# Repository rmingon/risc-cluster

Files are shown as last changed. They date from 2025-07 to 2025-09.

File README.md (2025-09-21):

# RISC-V Cluster Project

A distributed computing cluster based on CH32V RISC-V microcontrollers with Ethernet connectivity.

[HACKADAY](https://hackaday.io/project/204036-13ghz-for-only-10-bucks)

[TINDIE](https://www.tindie.com/products/rmingon/risc-v-cluster-13ghz-combined/)

REAL WORK

## Overview

This project implements a cluster computing system using multiple CH32V microcontrollers connected via Ethernet. The system features a master controller (CH32V307RCT6) that coordinates with multiple worker nodes (CH32V003F4P6) to form a distributed computing network.

## Project pictures

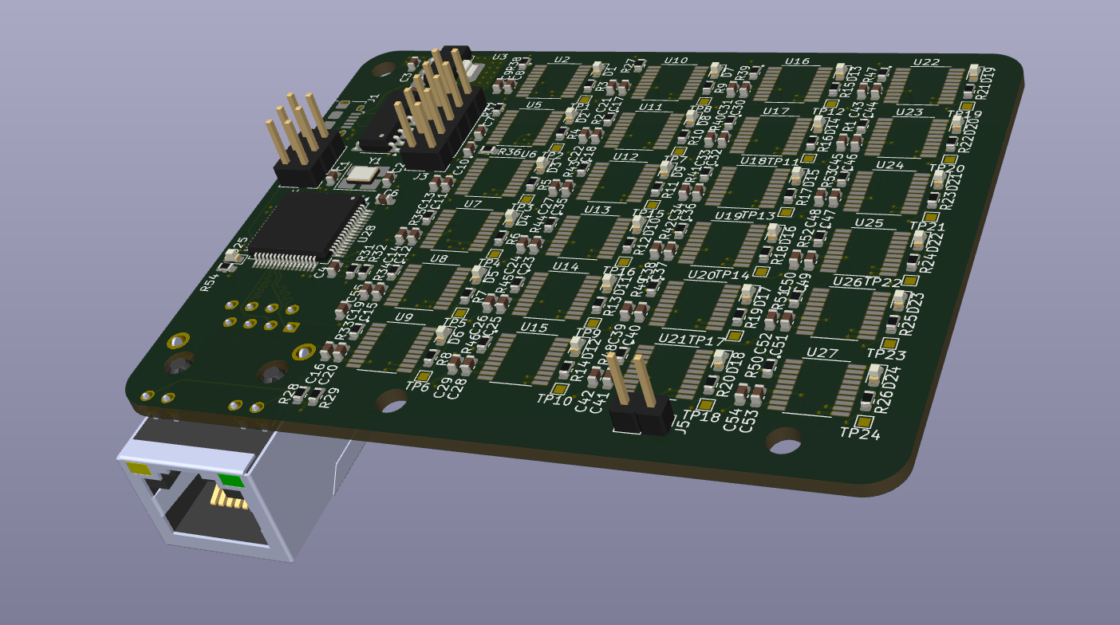
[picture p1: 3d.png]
3D

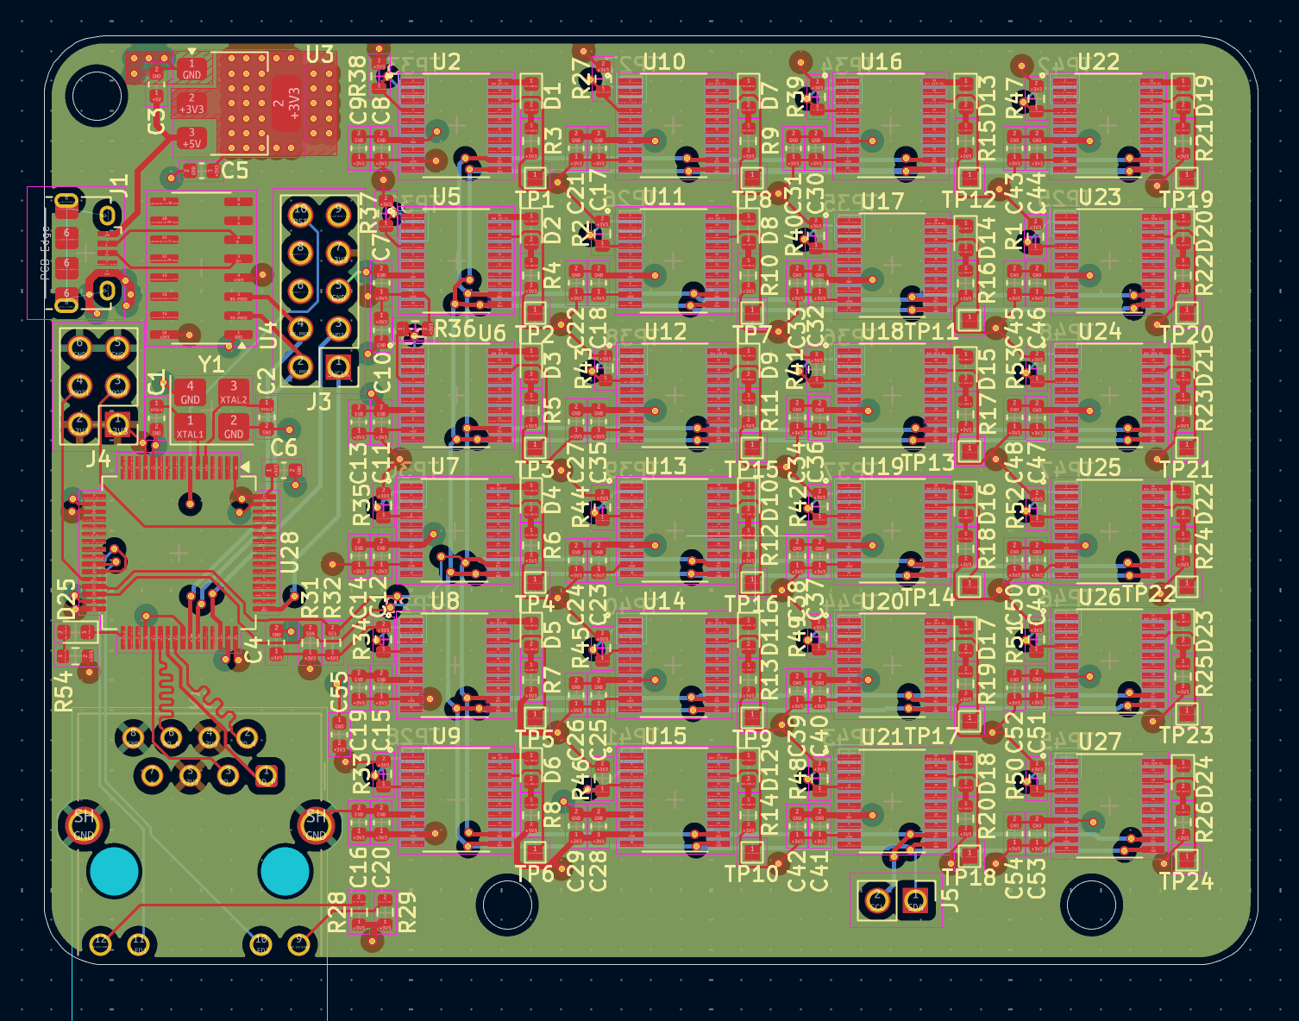
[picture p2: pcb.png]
pcb

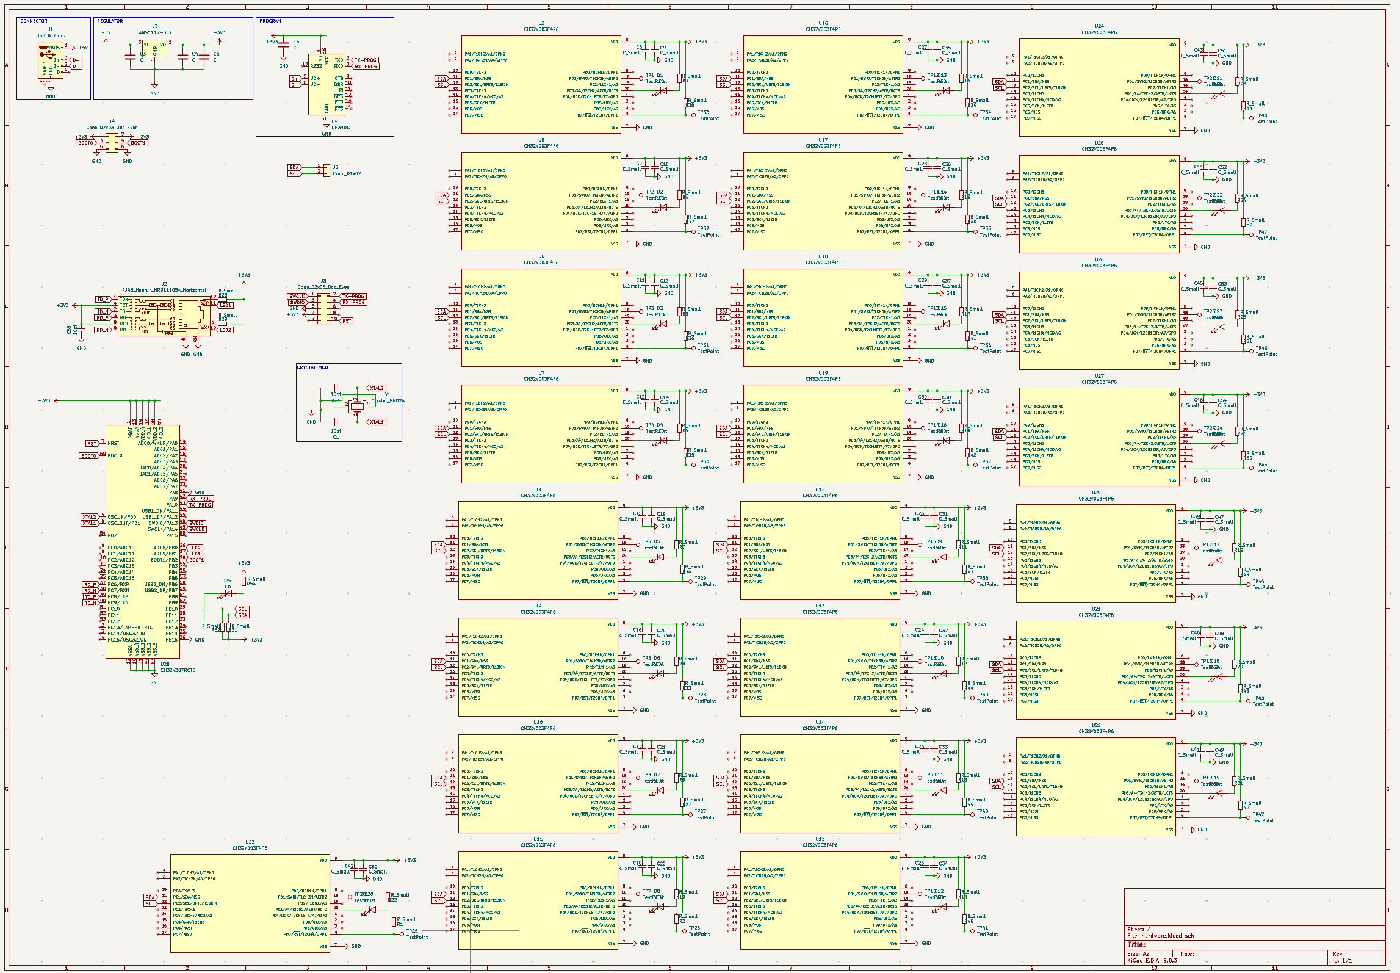
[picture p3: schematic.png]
schematic


## Hardware Design

### Master Controller

- **MCU**: CH32V307RCT6 (64-pin LQFP)
- **Features**:
  - RISC-V core with Ethernet MAC
  - USB connectivity for debugging and programming
  - Ethernet port (RJ45) for network communication
  - Power regulation (3.3V via AMS1117)

### Worker Nodes

- **MCU**: CH32V003F4P6 (24 units)
- **Features**:
  - Compact RISC-V microcontrollers
  - Individual LED indicators
  - Test points for debugging
  - Distributed across the PCB

### Key Components

- **Ethernet**: RJ45 connector with integrated magnetics
- **USB**: Micro-B connector for programming and debug
- **Power**: 3.3V regulation from USB input
- **Debug**: CH340C USB-to-UART bridge
- **Connectors**: Programming headers for JTAG/SWD access

## Project Structure

```
risc-cluster/
├── hardware/                 # KiCad PCB design files
│   ├── hardware.kicad_*     # Main PCB design files
│   ├── production/          # Manufacturing files
│   │   ├── bom.csv         # Bill of Materials
│   │   ├── positions.csv   # Pick and place data
│   │   └── hardware.zip    # Gerber files
│   └── hardware-backups/   # Design history backups
└── master/                  # Master controller firmware
    ├── Core/               # RISC-V core files
    ├── Debug/              # Debug utilities
    ├── Peripheral/         # CH32V30x peripheral drivers
    ├── Startup/            # Boot code
    └── User/               # Application code
```

## Bill of Materials

| Component | Quantity | Description |
| --- | --- | --- |
| CH32V307RCT6 | 1 | Master RISC-V MCU (LQFP-64) |
| CH32V003F4P6 | 24 | Worker RISC-V MCUs (SOP-20) |
| AMS1117-3.3  | 1 | 3.3V voltage regulator |
| CH340C | 1 | USB-to-UART bridge |
| LEDs | 25 | Status indicators |
| Resistors | 29 | Current limiting (0603) |
| Capacitors | 52 | Decoupling and filtering (0603) |
| Connectors | 5 | USB, Ethernet, programming headers |

## Development Setup

### Hardware Tools

- KiCad 7.0+ for PCB design
- Standard PCB fabrication (4-layer board)
- Pick and place assembly for SMD components

### Software Tools

- MounRiver Studio IDE (for CH32V development)
- WCH-LinkE programmer/debugger
- CH32V peripheral library

## Getting Started

1. **Hardware Assembly**: Use the production files in `hardware/production/` for PCB fabrication
2. **Master Firmware**: Build and flash the master controller code in `master/`
3. **Worker Firmware**: Develop and deploy worker node firmware for distributed tasks
4. **Network Setup**: Configure Ethernet connectivity for cluster communication

## Recent Development

Based on git history, recent work includes:

- Initial PCB layout with CH32V microcontrollers
- Ethernet connectivity implementation
- CH32V307 master controller integration
- MounRiver Studio project setup
- Production file generation

## License

This project is licensed under the CERN Open Hardware Licence Version 2 - Strongly Reciprocal (CERN-OHL-S v2).

The hardware design files are released under CERN-OHL-S v2, which ensures that any modifications or improvements to the hardware design must be shared under the same license terms.

Note: This project uses WCH (Nanjing Qinheng Microelectronics) peripheral libraries for firmware development, which are subject to their own licensing terms.

## Contributing

This is a hardware-software co-design project. Contributions welcome for:

- Firmware optimization
- Hardware design improvements
- Cluster algorithms implementation
- Documentation and examples

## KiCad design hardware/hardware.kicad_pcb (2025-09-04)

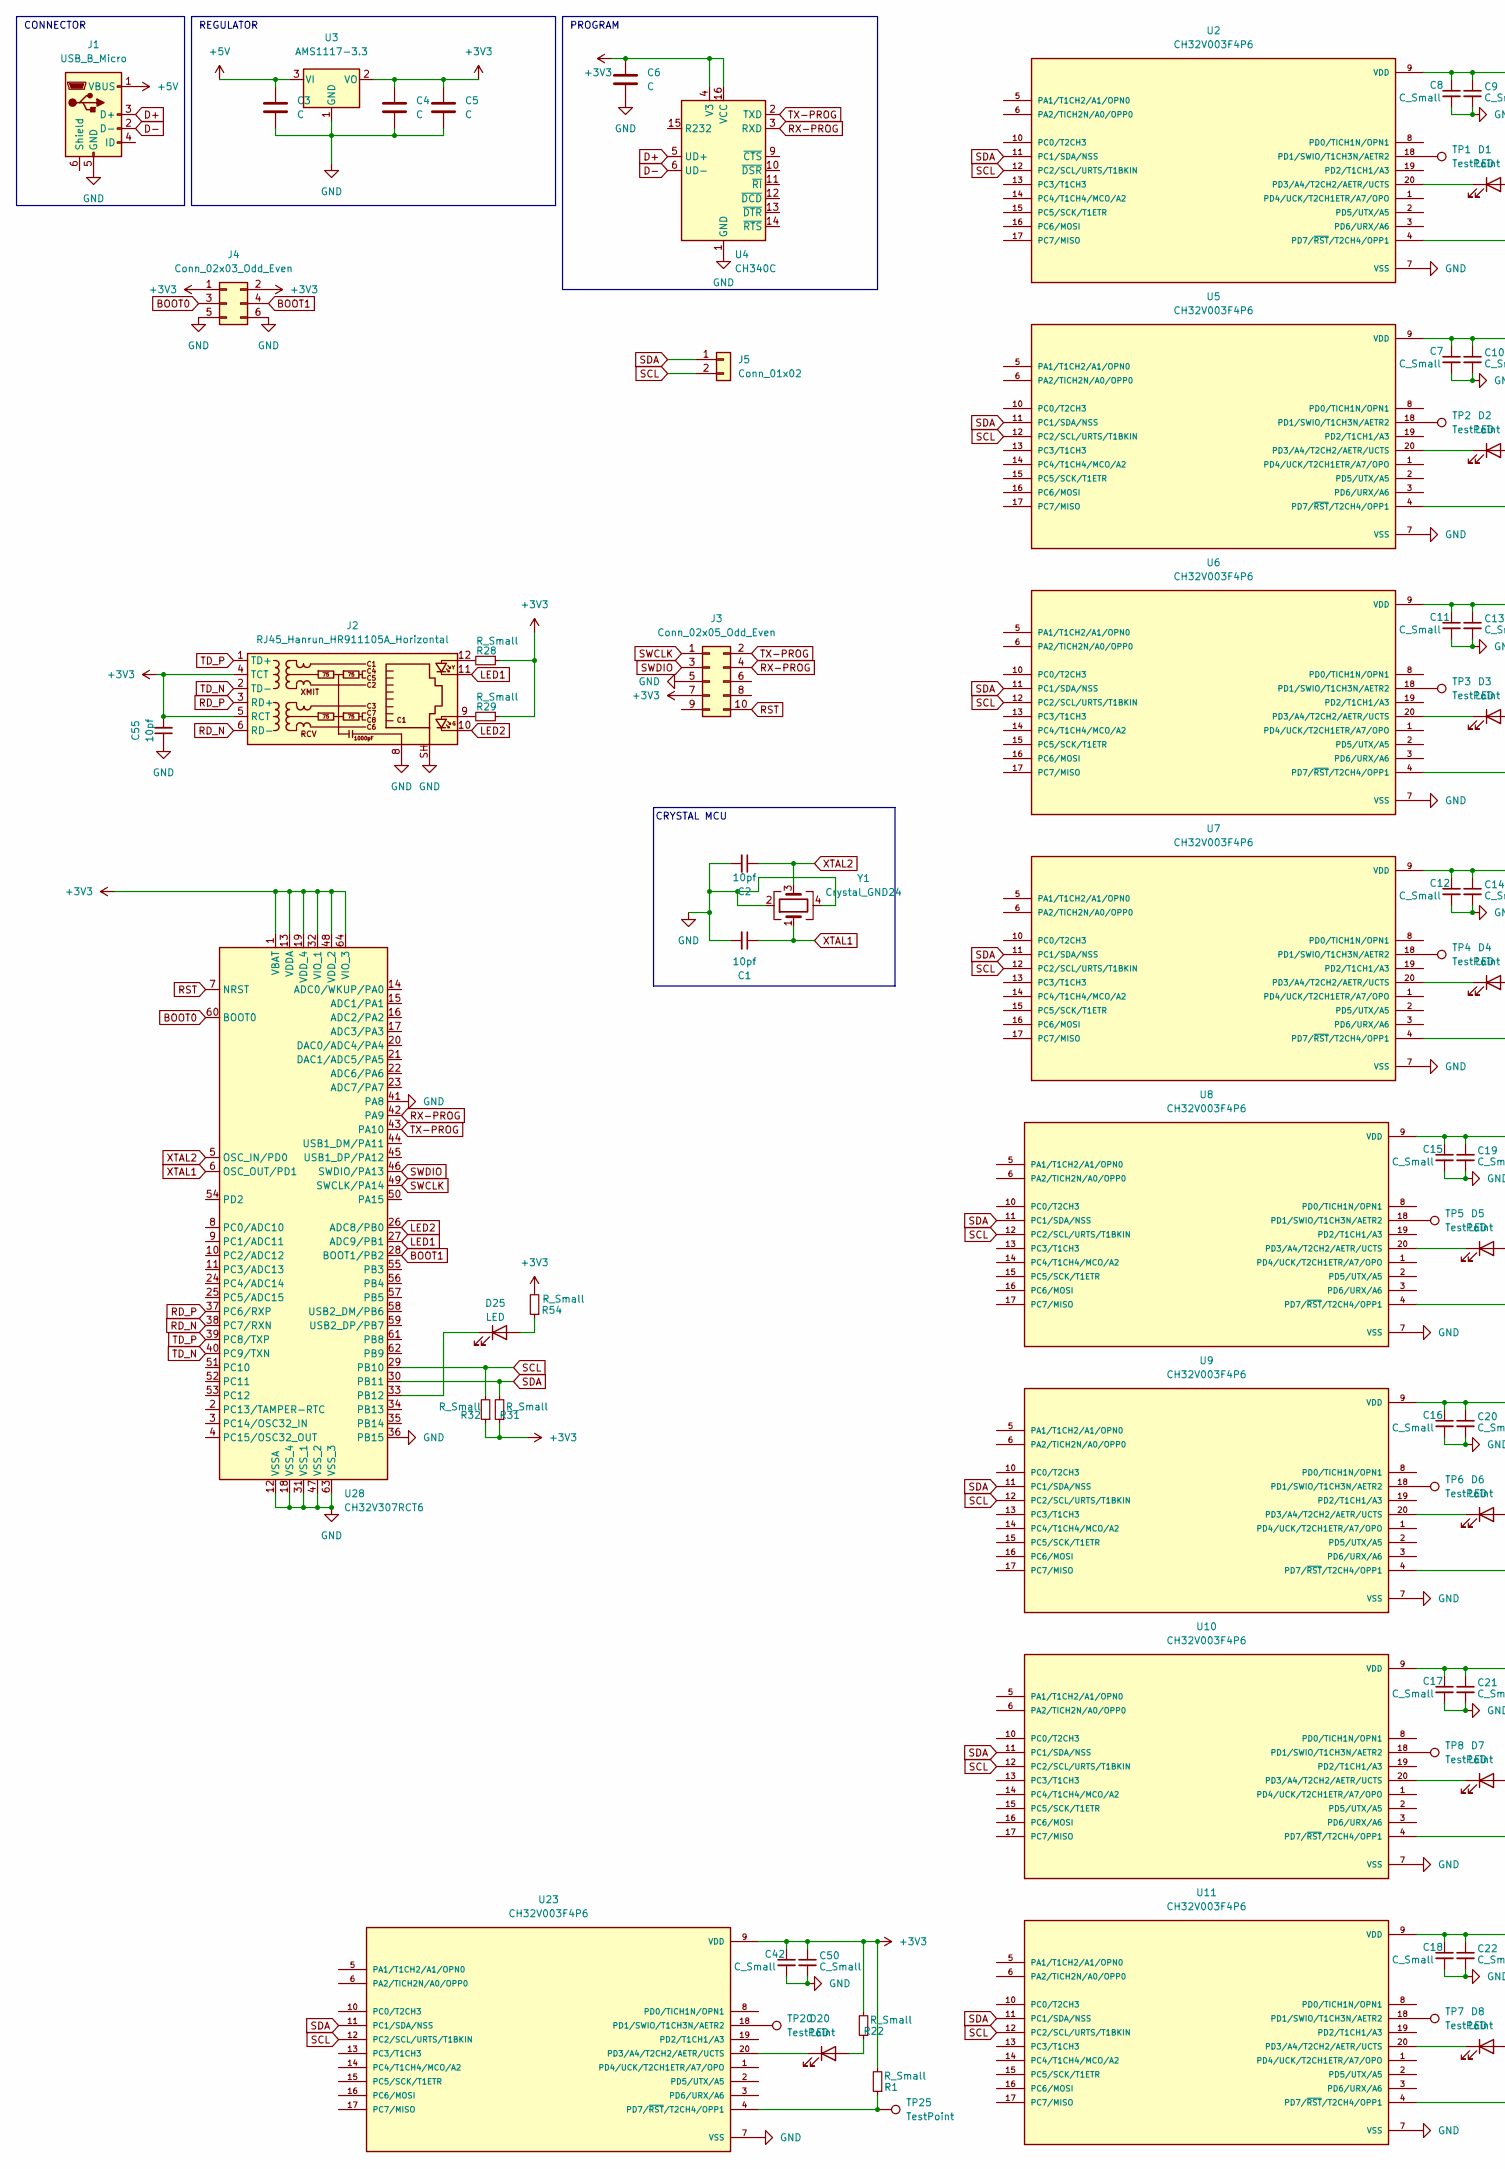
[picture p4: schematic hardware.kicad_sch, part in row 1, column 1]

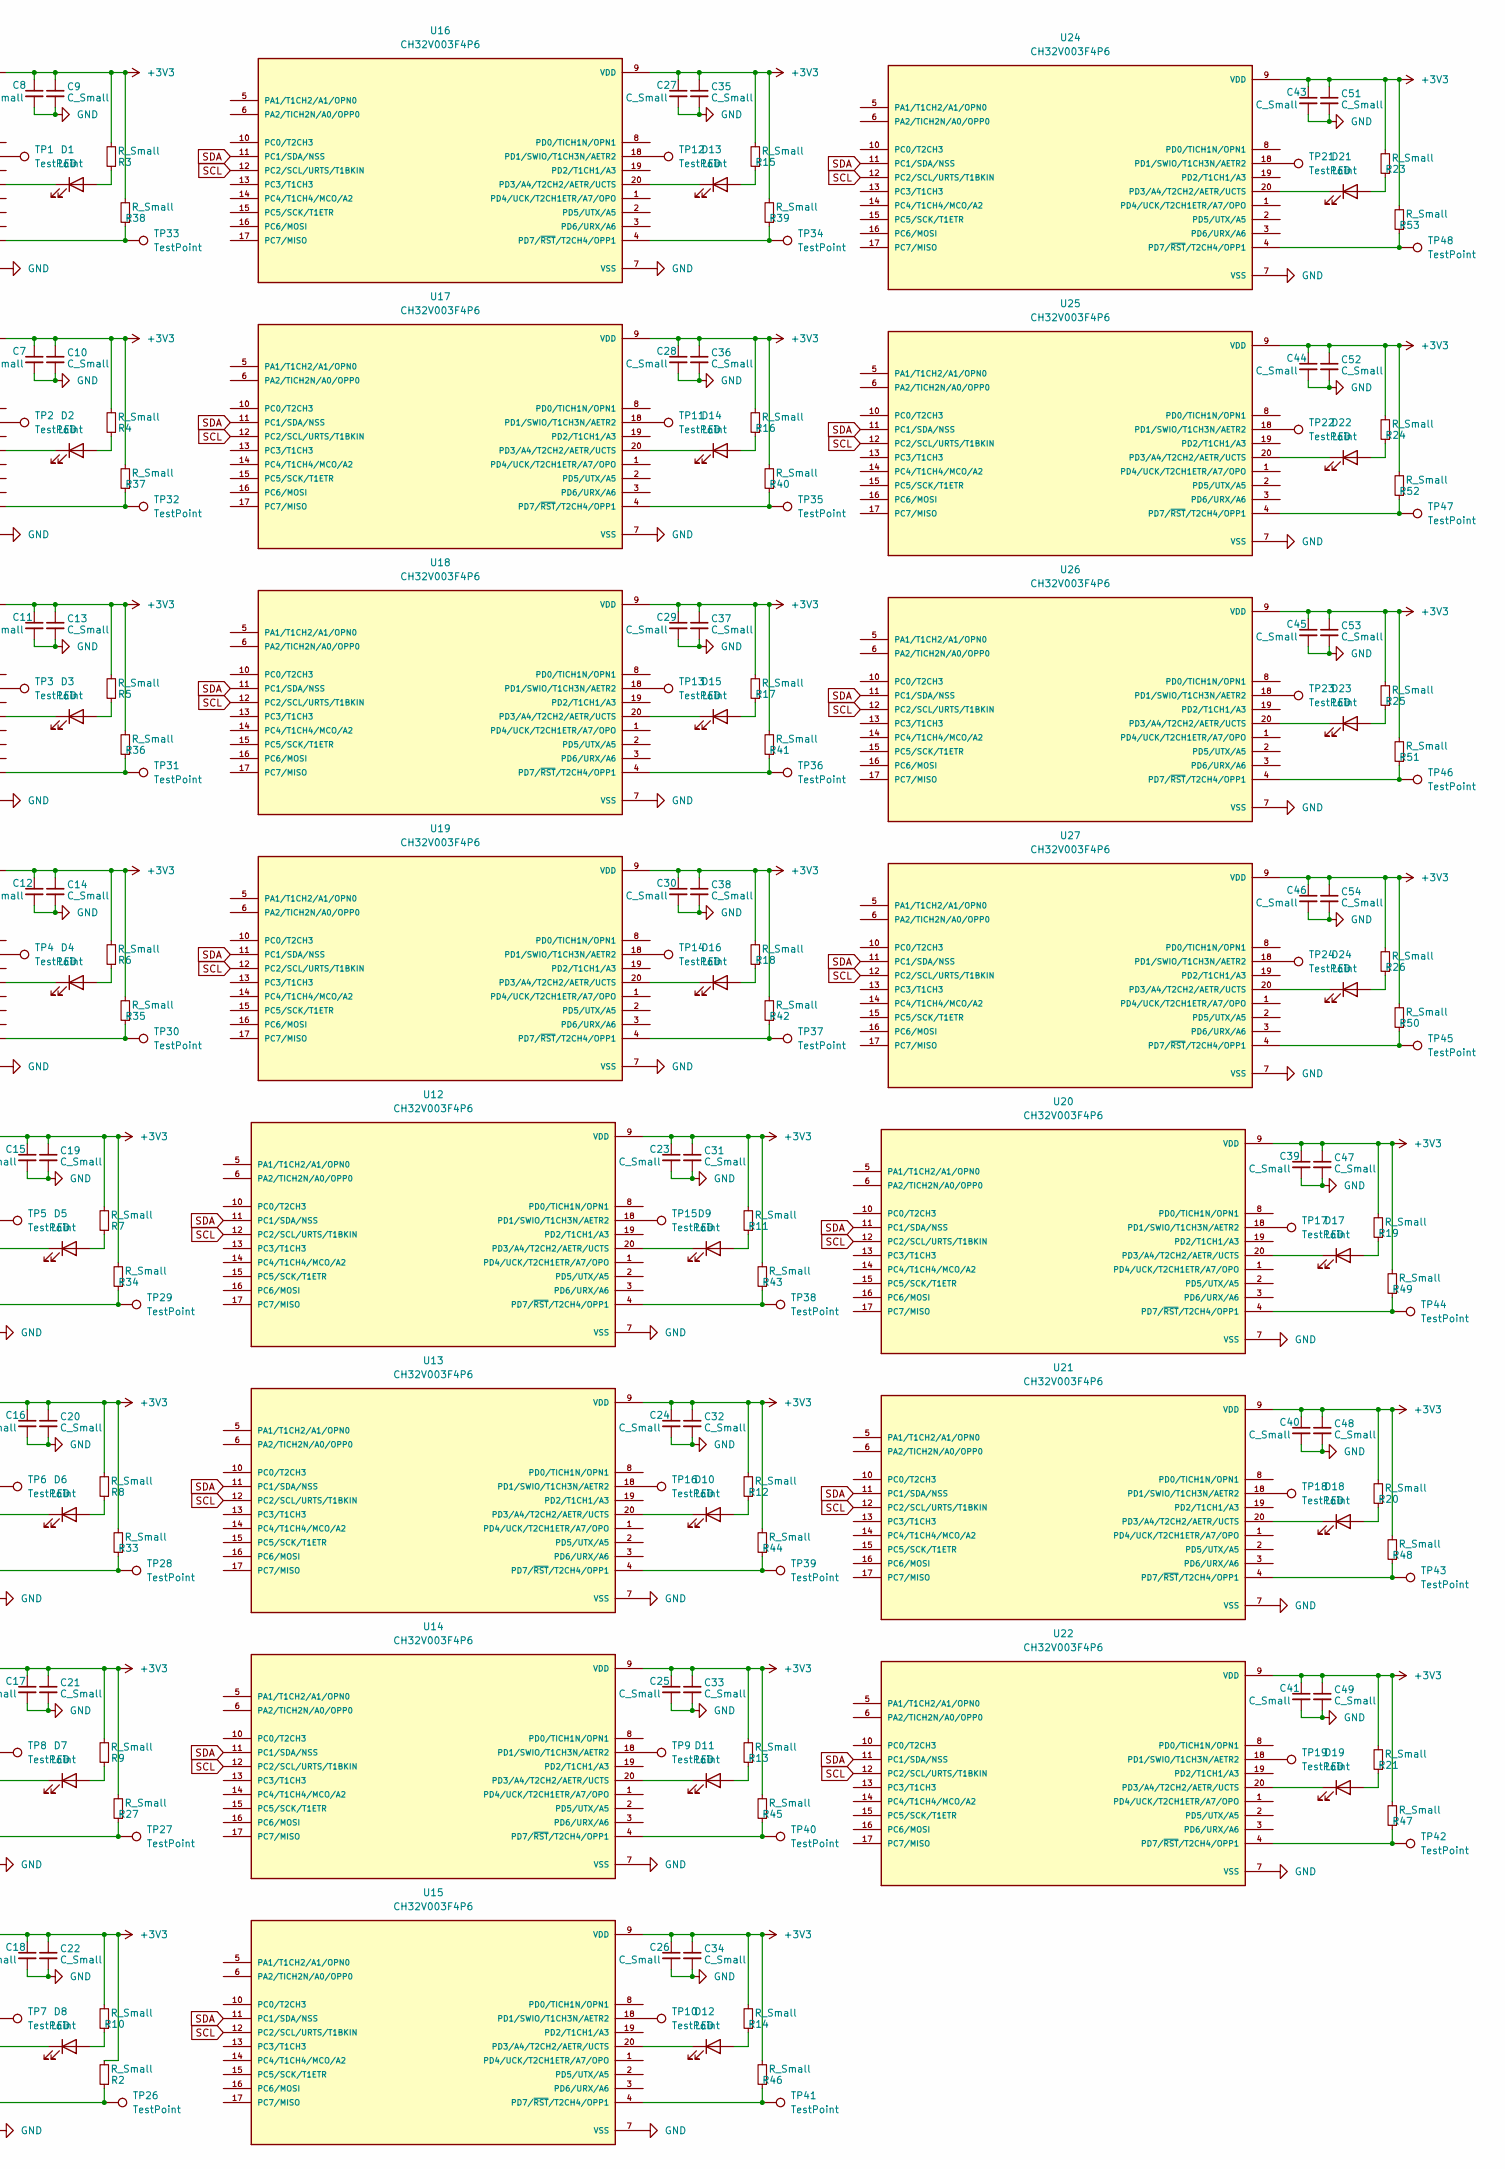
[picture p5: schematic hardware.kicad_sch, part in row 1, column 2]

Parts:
C1, C2, C55: 10pf; C_0603_1608Metric; LCSC C106245
C3, C4, C5, C6: C; C_0603_1608Metric
C7, C8, C9, C10, C11, C12, C13, C14, C15, C16, C17, C18, C19, C20, C21, C22, C23, C24, C25, C26, C27, C28, C29, C30, C31, C32, C33, C34, C35, C36, C37, C38, C39, C40, C41, C42, C43, C44, C45, C46, C47, C48, C49, C50, C51, C52, C53, C54: C_Small; C_0603_1608Metric
D1, D2, D3, D4, D5, D6, D7, D8, D9, D10, D11, D12, D13, D14, D15, D16, D17, D18, D19, D20, D21, D22, D23, D24, D25: LED; LED_0603_1608Metric
J1: USB_B_Micro; USB_Micro-B_Amphenol_10118194_Horizontal
J2: RJ45_Hanrun_HR911105A_Horizontal
J3: Conn_02x05_Odd_Even; PinHeader_2x05_P2.54mm_Vertical
J4: Conn_02x03_Odd_Even; PinHeader_2x03_P2.54mm_Vertical
J5: Conn_01x02; PinHeader_1x02_P2.54mm_Vertical
R1, R2, R3, R4, R5, R6, R7, R8, R9, R10, R11, R12, R13, R14, R15, R16, R17, R18, R19, R20, R21, R22, R23, R24, R25, R26, R27, R28, R29, R31, R32, R33, R34, R35, R36, R37, R38, R39, R40, R41, R42, R43, R44, R45, R46, R47, R48, R49, R50, R51, R52, R53, R54: R_Small; R_0603_1608Metric
TP1, TP2, TP3, TP4, TP5, TP6, TP7, TP8, TP9, TP10, TP11, TP12, TP13, TP14, TP15, TP16, TP17, TP18, TP19, TP20, TP21, TP22, TP23, TP24, TP25, TP26, TP27, TP28, TP29, TP30, TP31, TP32, TP33, TP34, TP35, TP36, TP37, TP38, TP39, TP40, TP41, TP42, TP43, TP44, TP45, TP46, TP47, TP48: TestPoint; TestPoint_Pad_1.0x1.0mm
U2, U5, U6, U7, U8, U9, U10, U11, U12, U13, U14, U15, U16, U17, U18, U19, U20, U21, U22, U23, U24, U25, U26, U27: CH32V003F4P6; SOP65P640X121-20N; PARTREV 1.4
U3: AMS1117-3.3; SOT-223-3_TabPin2
U4: CH340C; SOIC-16_3.9x9.9mm_P1.27mm
U28: CH32V307RCT6; LQFP-64_10x10mm_P0.5mm
Y1: Crystal_GND24; Crystal_SMD_3225-4Pin_3.2x2.5mm_HandSoldering

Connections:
+3V3: C4.1, C5.1, C6.1, C7.1, C8.1, C9.1, C10.1, C11.1, C12.1, C13.1, C14.1, C15.1, C16.1, C17.1, C18.1, C19.1, C20.1, C21.1, C22.1, C23.1, C24.1, C25.1, C26.1, C27.1, C28.1, C29.1, C30.1, C31.1, C32.1, C33.1, C34.1, C35.1, C36.1, C37.1, C38.1, C39.1, C40.1, C41.1, C42.1, C43.1, C44.1, C45.1, C46.1, C47.1, C48.1, C49.1, C50.1, C51.1, C52.1, C53.1, C54.1, C55.2, J2.4 (TCT), J2.5 (RCT), J3.7, J4.1, J4.2, R1.2, R2.2, R3.2, R4.2, R5.2, R6.2, R7.2, R8.2, R9.2, R10.2, R11.2, R12.2, R13.2, R14.2, R15.2, R16.2, R17.2, R18.2, R19.2, R20.2, R21.2, R22.2, R23.2, R24.2, R25.2, R26.2, R27.2, R28.1, R29.1, R31.1, R32.1, R33.2, R34.2, R35.2, R36.2, R37.2, R38.2, R39.2, R40.2, R41.2, R42.2, R43.2, R44.2, R45.2, R46.2, R47.2, R48.2, R49.2, R50.2, R51.2, R52.2, R53.2, R54.2, U2.9 (VDD), U3.2 (VO), U4.4 (V3), U4.16 (VCC), U5.9 (VDD), U6.9 (VDD), U7.9 (VDD), U8.9 (VDD), U9.9 (VDD), U10.9 (VDD), U11.9 (VDD), U12.9 (VDD), U13.9 (VDD), U14.9 (VDD), U15.9 (VDD), U16.9 (VDD), U17.9 (VDD), U18.9 (VDD), U19.9 (VDD), U20.9 (VDD), U21.9 (VDD), U22.9 (VDD), U23.9 (VDD), U24.9 (VDD), U25.9 (VDD), U26.9 (VDD), U27.9 (VDD), U28.1 (VBAT), U28.13 (VDDA), U28.19 (VDD_4), U28.32 (VIO_1), U28.48 (VDD_2), U28.64 (VIO_3)
+5V: C3.1, J1.1 (VBUS), U3.3 (VI)
BOOT0: J4.3, U28.60 (BOOT0)
BOOT1: J4.4, U28.28 (BOOT1/PB2)
D+: J1.3 (D+), U4.5 (UD+)
D-: J1.2 (D-), U4.6 (UD-)
GND: C1.2, C2.2, C3.2, C4.2, C5.2, C6.2, C7.2, C8.2, C9.2, C10.2, C11.2, C12.2, C13.2, C14.2, C15.2, C16.2, C17.2, C18.2, C19.2, C20.2, C21.2, C22.2, C23.2, C24.2, C25.2, C26.2, C27.2, C28.2, C29.2, C30.2, C31.2, C32.2, C33.2, C34.2, C35.2, C36.2, C37.2, C38.2, C39.2, C40.2, C41.2, C42.2, C43.2, C44.2, C45.2, C46.2, C47.2, C48.2, C49.2, C50.2, C51.2, C52.2, C53.2, C54.2, C55.1, J1.5 (GND), J2.8, J2.SH, J3.5, J4.5, J4.6, U2.7 (VSS), U3.1 (GND), U4.1 (GND), U5.7 (VSS), U6.7 (VSS), U7.7 (VSS), U8.7 (VSS), U9.7 (VSS), U10.7 (VSS), U11.7 (VSS), U12.7 (VSS), U13.7 (VSS), U14.7 (VSS), U15.7 (VSS), U16.7 (VSS), U17.7 (VSS), U18.7 (VSS), U19.7 (VSS), U20.7 (VSS), U21.7 (VSS), U22.7 (VSS), U23.7 (VSS), U24.7 (VSS), U25.7 (VSS), U26.7 (VSS), U27.7 (VSS), U28.12 (VSSA), U28.18 (VSS_4), U28.31 (VSS_1), U28.36 (PB15), U28.41 (PA8), U28.47 (VSS_2), U28.63 (VSS_3), Y1.2, Y1.4
LED1: J2.11, U28.27 (ADC9/PB1)
LED2: J2.10, U28.26 (ADC8/PB0)
unnamed: D1.2 (A), R3.1
unnamed: D1.1 (K), U2.20 (PD3/A4/T2CH2/AETR/UCTS)
unnamed: D2.2 (A), R4.1
unnamed: D2.1 (K), U5.20 (PD3/A4/T2CH2/AETR/UCTS)
unnamed: D3.2 (A), R5.1
unnamed: D3.1 (K), U6.20 (PD3/A4/T2CH2/AETR/UCTS)
unnamed: D4.2 (A), R6.1
unnamed: D4.1 (K), U7.20 (PD3/A4/T2CH2/AETR/UCTS)
unnamed: D5.2 (A), R7.1
unnamed: D5.1 (K), U8.20 (PD3/A4/T2CH2/AETR/UCTS)
unnamed: D6.2 (A), R8.1
unnamed: D6.1 (K), U9.20 (PD3/A4/T2CH2/AETR/UCTS)
unnamed: D7.2 (A), R9.1
unnamed: D7.1 (K), U10.20 (PD3/A4/T2CH2/AETR/UCTS)
unnamed: D8.2 (A), R10.1
unnamed: D8.1 (K), U11.20 (PD3/A4/T2CH2/AETR/UCTS)
unnamed: D9.2 (A), R11.1
unnamed: D9.1 (K), U12.20 (PD3/A4/T2CH2/AETR/UCTS)
unnamed: D10.2 (A), R12.1
unnamed: D10.1 (K), U13.20 (PD3/A4/T2CH2/AETR/UCTS)
unnamed: D11.2 (A), R13.1
unnamed: D11.1 (K), U14.20 (PD3/A4/T2CH2/AETR/UCTS)
unnamed: D12.2 (A), R14.1
unnamed: D12.1 (K), U15.20 (PD3/A4/T2CH2/AETR/UCTS)
unnamed: D13.2 (A), R15.1
unnamed: D13.1 (K), U16.20 (PD3/A4/T2CH2/AETR/UCTS)
unnamed: D14.2 (A), R16.1
unnamed: D14.1 (K), U17.20 (PD3/A4/T2CH2/AETR/UCTS)
unnamed: D15.2 (A), R17.1
unnamed: D15.1 (K), U18.20 (PD3/A4/T2CH2/AETR/UCTS)
unnamed: D16.2 (A), R18.1
unnamed: D16.1 (K), U19.20 (PD3/A4/T2CH2/AETR/UCTS)
unnamed: D17.2 (A), R19.1
unnamed: D17.1 (K), U20.20 (PD3/A4/T2CH2/AETR/UCTS)
unnamed: D18.2 (A), R20.1
unnamed: D18.1 (K), U21.20 (PD3/A4/T2CH2/AETR/UCTS)
unnamed: D19.2 (A), R21.1
unnamed: D19.1 (K), U22.20 (PD3/A4/T2CH2/AETR/UCTS)
unnamed: D20.2 (A), R22.1
unnamed: D20.1 (K), U23.20 (PD3/A4/T2CH2/AETR/UCTS)
unnamed: D21.2 (A), R23.1
unnamed: D21.1 (K), U24.20 (PD3/A4/T2CH2/AETR/UCTS)
unnamed: D22.2 (A), R24.1
unnamed: D22.1 (K), U25.20 (PD3/A4/T2CH2/AETR/UCTS)
unnamed: D23.2 (A), R25.1
unnamed: D23.1 (K), U26.20 (PD3/A4/T2CH2/AETR/UCTS)
unnamed: D24.2 (A), R26.1
unnamed: D24.1 (K), U27.20 (PD3/A4/T2CH2/AETR/UCTS)
unnamed: D25.2 (A), R54.1
unnamed: D25.1 (K), U28.33 (PB12)
unnamed: J2.9, R29.2
unnamed: J2.12, R28.2
unnamed: TP1.1, U2.18 (PD1/SWIO/T1CH3N/AETR2)
unnamed: R38.1, TP33.1, U2.4 (PD7/~RST/T2CH4/OPP1)
unnamed: TP2.1, U5.18 (PD1/SWIO/T1CH3N/AETR2)
unnamed: R37.1, TP32.1, U5.4 (PD7/~RST/T2CH4/OPP1)
unnamed: TP3.1, U6.18 (PD1/SWIO/T1CH3N/AETR2)
unnamed: R36.1, TP31.1, U6.4 (PD7/~RST/T2CH4/OPP1)
unnamed: TP4.1, U7.18 (PD1/SWIO/T1CH3N/AETR2)
unnamed: R35.1, TP30.1, U7.4 (PD7/~RST/T2CH4/OPP1)
unnamed: TP5.1, U8.18 (PD1/SWIO/T1CH3N/AETR2)
unnamed: R34.1, TP29.1, U8.4 (PD7/~RST/T2CH4/OPP1)
unnamed: TP6.1, U9.18 (PD1/SWIO/T1CH3N/AETR2)
unnamed: R33.1, TP28.1, U9.4 (PD7/~RST/T2CH4/OPP1)
unnamed: TP8.1, U10.18 (PD1/SWIO/T1CH3N/AETR2)
unnamed: R27.1, TP27.1, U10.4 (PD7/~RST/T2CH4/OPP1)
unnamed: TP7.1, U11.18 (PD1/SWIO/T1CH3N/AETR2)
unnamed: R2.1, TP26.1, U11.4 (PD7/~RST/T2CH4/OPP1)
unnamed: TP15.1, U12.18 (PD1/SWIO/T1CH3N/AETR2)
unnamed: R43.1, TP38.1, U12.4 (PD7/~RST/T2CH4/OPP1)
unnamed: TP16.1, U13.18 (PD1/SWIO/T1CH3N/AETR2)
unnamed: R44.1, TP39.1, U13.4 (PD7/~RST/T2CH4/OPP1)
unnamed: TP9.1, U14.18 (PD1/SWIO/T1CH3N/AETR2)
unnamed: R45.1, TP40.1, U14.4 (PD7/~RST/T2CH4/OPP1)
unnamed: TP10.1, U15.18 (PD1/SWIO/T1CH3N/AETR2)
unnamed: R46.1, TP41.1, U15.4 (PD7/~RST/T2CH4/OPP1)
unnamed: TP12.1, U16.18 (PD1/SWIO/T1CH3N/AETR2)
unnamed: R39.1, TP34.1, U16.4 (PD7/~RST/T2CH4/OPP1)
unnamed: TP11.1, U17.18 (PD1/SWIO/T1CH3N/AETR2)
unnamed: R40.1, TP35.1, U17.4 (PD7/~RST/T2CH4/OPP1)
unnamed: TP13.1, U18.18 (PD1/SWIO/T1CH3N/AETR2)
unnamed: R41.1, TP36.1, U18.4 (PD7/~RST/T2CH4/OPP1)
unnamed: TP14.1, U19.18 (PD1/SWIO/T1CH3N/AETR2)
unnamed: R42.1, TP37.1, U19.4 (PD7/~RST/T2CH4/OPP1)
unnamed: TP17.1, U20.18 (PD1/SWIO/T1CH3N/AETR2)
unnamed: R49.1, TP44.1, U20.4 (PD7/~RST/T2CH4/OPP1)
unnamed: TP18.1, U21.18 (PD1/SWIO/T1CH3N/AETR2)
unnamed: R48.1, TP43.1, U21.4 (PD7/~RST/T2CH4/OPP1)
unnamed: TP19.1, U22.18 (PD1/SWIO/T1CH3N/AETR2)
unnamed: R47.1, TP42.1, U22.4 (PD7/~RST/T2CH4/OPP1)
unnamed: TP20.1, U23.18 (PD1/SWIO/T1CH3N/AETR2)
unnamed: R1.1, TP25.1, U23.4 (PD7/~RST/T2CH4/OPP1)
unnamed: TP21.1, U24.18 (PD1/SWIO/T1CH3N/AETR2)
unnamed: R53.1, TP48.1, U24.4 (PD7/~RST/T2CH4/OPP1)
unnamed: TP22.1, U25.18 (PD1/SWIO/T1CH3N/AETR2)
unnamed: R52.1, TP47.1, U25.4 (PD7/~RST/T2CH4/OPP1)
unnamed: TP23.1, U26.18 (PD1/SWIO/T1CH3N/AETR2)
unnamed: R51.1, TP46.1, U26.4 (PD7/~RST/T2CH4/OPP1)
unnamed: TP24.1, U27.18 (PD1/SWIO/T1CH3N/AETR2)
unnamed: R50.1, TP45.1, U27.4 (PD7/~RST/T2CH4/OPP1)
RD_N: J2.6 (RD-), U28.38 (PC7/RXN)
RD_P: J2.3 (RD+), U28.37 (PC6/RXP)
RST: J3.10, U28.7 (NRST)
RX-PROG: J3.4, U4.3 (RXD), U28.42 (PA9)
SCL: J5.2, R32.2, U2.12 (PC2/SCL/URTS/T1BKIN), U5.12 (PC2/SCL/URTS/T1BKIN), U6.12 (PC2/SCL/URTS/T1BKIN), U7.12 (PC2/SCL/URTS/T1BKIN), U8.12 (PC2/SCL/URTS/T1BKIN), U9.12 (PC2/SCL/URTS/T1BKIN), U10.12 (PC2/SCL/URTS/T1BKIN), U11.12 (PC2/SCL/URTS/T1BKIN), U12.12 (PC2/SCL/URTS/T1BKIN), U13.12 (PC2/SCL/URTS/T1BKIN), U14.12 (PC2/SCL/URTS/T1BKIN), U15.12 (PC2/SCL/URTS/T1BKIN), U16.12 (PC2/SCL/URTS/T1BKIN), U17.12 (PC2/SCL/URTS/T1BKIN), U18.12 (PC2/SCL/URTS/T1BKIN), U19.12 (PC2/SCL/URTS/T1BKIN), U20.12 (PC2/SCL/URTS/T1BKIN), U21.12 (PC2/SCL/URTS/T1BKIN), U22.12 (PC2/SCL/URTS/T1BKIN), U23.12 (PC2/SCL/URTS/T1BKIN), U24.12 (PC2/SCL/URTS/T1BKIN), U25.12 (PC2/SCL/URTS/T1BKIN), U26.12 (PC2/SCL/URTS/T1BKIN), U27.12 (PC2/SCL/URTS/T1BKIN), U28.29 (PB10)
SDA: J5.1, R31.2, U2.11 (PC1/SDA/NSS), U5.11 (PC1/SDA/NSS), U6.11 (PC1/SDA/NSS), U7.11 (PC1/SDA/NSS), U8.11 (PC1/SDA/NSS), U9.11 (PC1/SDA/NSS), U10.11 (PC1/SDA/NSS), U11.11 (PC1/SDA/NSS), U12.11 (PC1/SDA/NSS), U13.11 (PC1/SDA/NSS), U14.11 (PC1/SDA/NSS), U15.11 (PC1/SDA/NSS), U16.11 (PC1/SDA/NSS), U17.11 (PC1/SDA/NSS), U18.11 (PC1/SDA/NSS), U19.11 (PC1/SDA/NSS), U20.11 (PC1/SDA/NSS), U21.11 (PC1/SDA/NSS), U22.11 (PC1/SDA/NSS), U23.11 (PC1/SDA/NSS), U24.11 (PC1/SDA/NSS), U25.11 (PC1/SDA/NSS), U26.11 (PC1/SDA/NSS), U27.11 (PC1/SDA/NSS), U28.30 (PB11)
SWCLK: J3.1, U28.49 (SWCLK/PA14)
SWDIO: J3.3, U28.46 (SWDIO/PA13)
TD_N: J2.2 (TD-), U28.40 (PC9/TXN)
TD_P: J2.1 (TD+), U28.39 (PC8/TXP)
TX-PROG: J3.2, U4.2 (TXD), U28.43 (PA10)
XTAL1: C1.1, U28.6 (OSC_OUT/PD1), Y1.1
XTAL2: C2.1, U28.5 (OSC_IN/PD0), Y1.3

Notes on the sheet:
CONNECTOR
PROGRAM
REGULATOR
CRYSTAL MCU

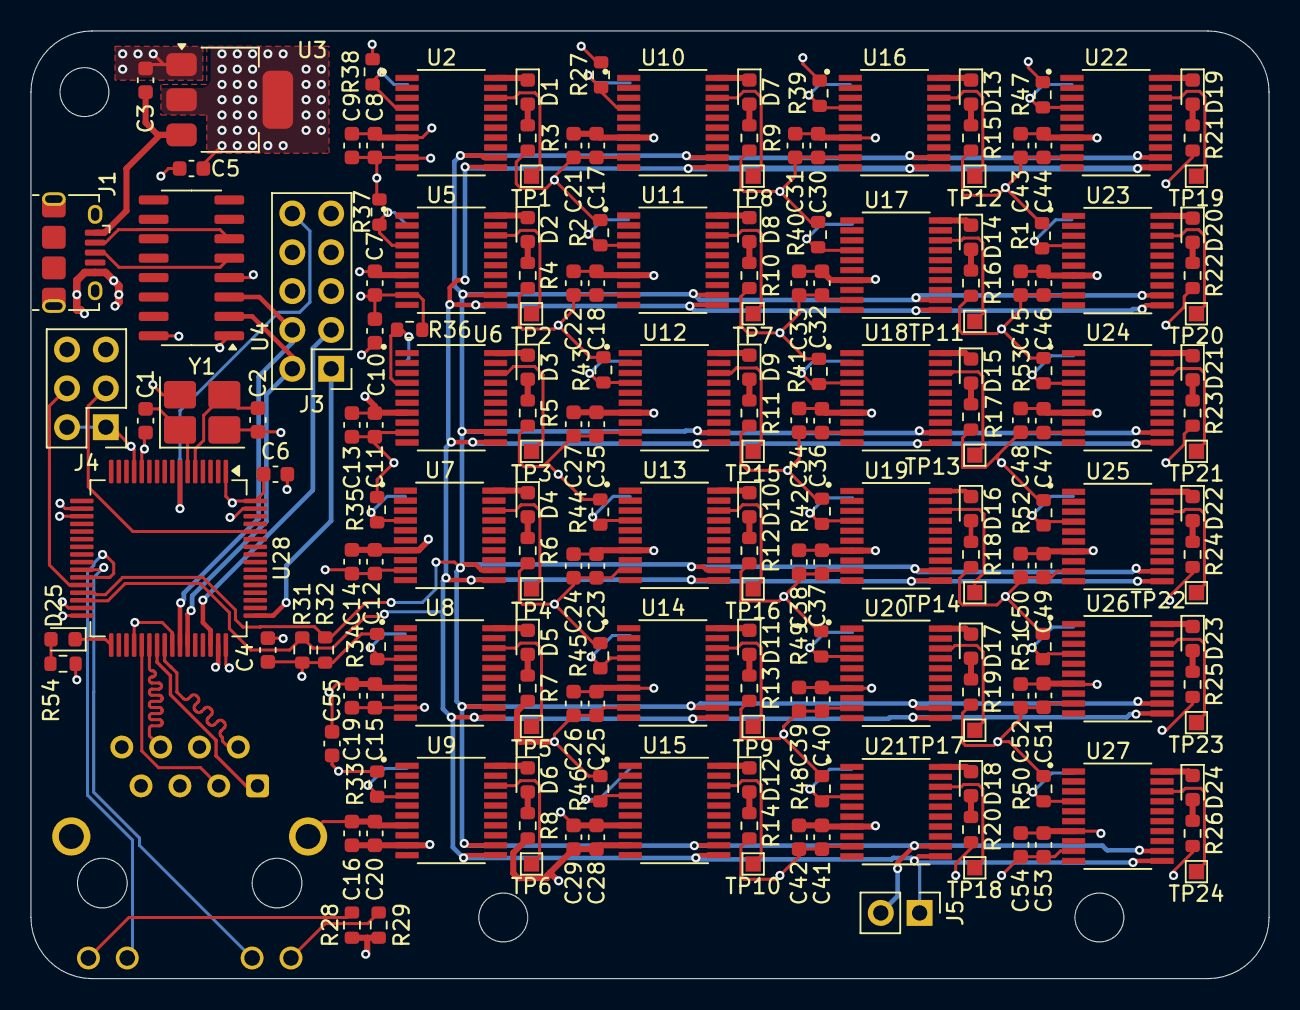
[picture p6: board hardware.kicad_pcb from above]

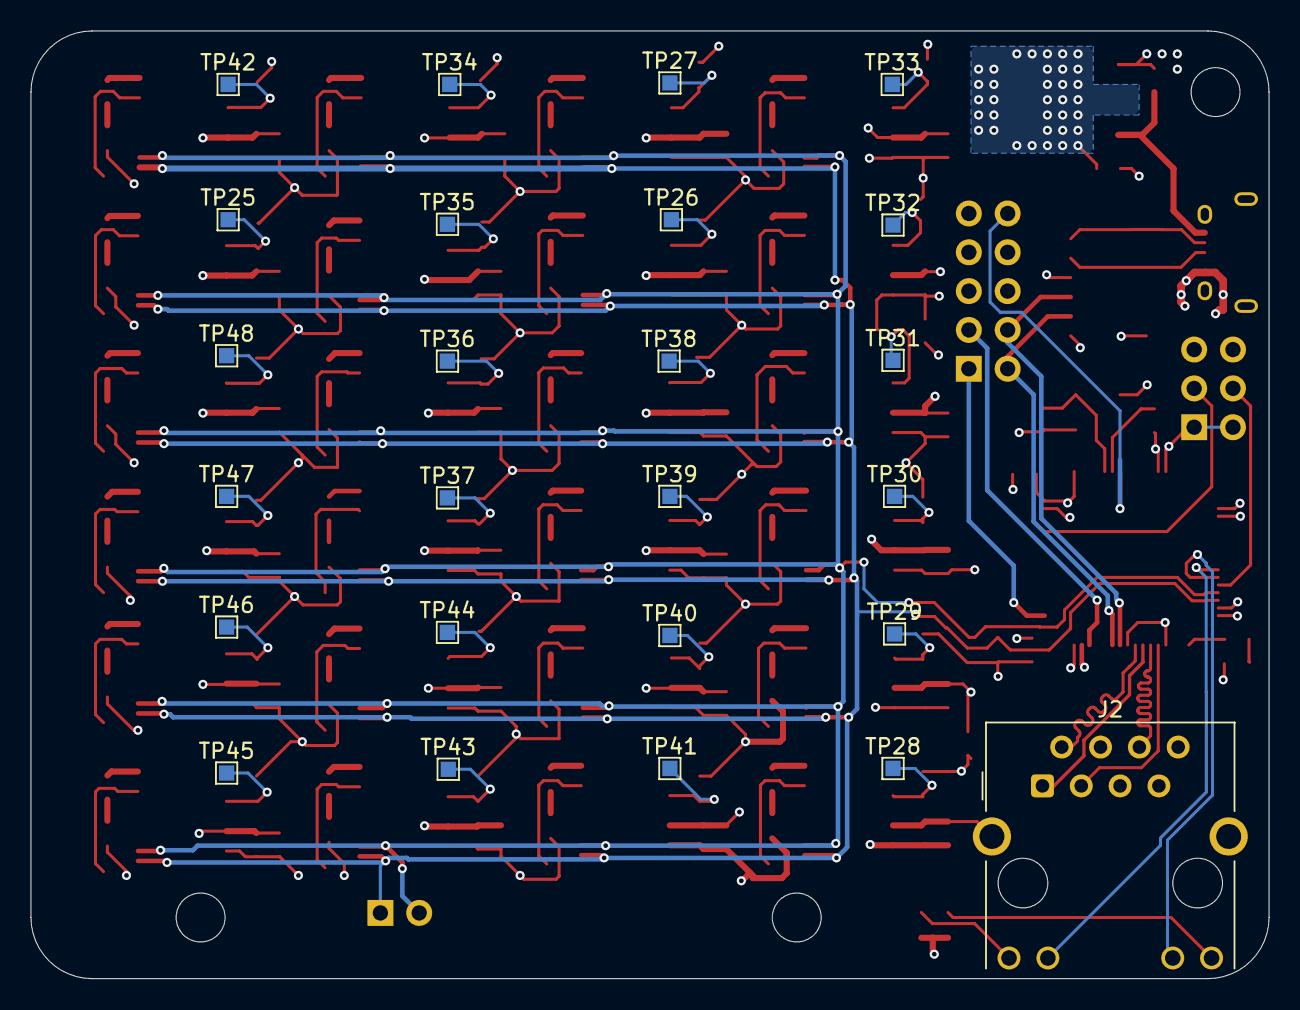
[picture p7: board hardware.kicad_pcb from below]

Board: 4 copper layers, 81.0 x 62.0 mm, 214 parts (25 on the bottom side), 122 nets.

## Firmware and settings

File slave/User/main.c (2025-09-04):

/*
 * CH32V006 Main Application (Updateable)
 * Memory Layout: 0x08001000 - 0x08008000 (28KB)
 * This is the application that gets updated via the bootloader
 */

#include "debug.h"

#define APPLICATION_VERSION    0x0102  // v1.02
#define I2C_SLAVE_ADDRESS      0x10
#define I2C_BUFFER_SIZE        128

#define APPLICATION_START      0x00002000  // Corrected from 0x08001000
#define BOOTLOADER_START       0x00000000  // Corrected from 0x08000000

// I2C State machine
typedef enum {
    I2C_STATE_IDLE = 0,
    I2C_STATE_ADDR_MATCH,
    I2C_STATE_RX_REG,
    I2C_STATE_RX_DATA,
    I2C_STATE_TX_DATA
} I2C_State_t;

// Global variables
volatile uint8_t i2c_registers[I2C_BUFFER_SIZE] = {0}; 
volatile uint8_t i2c_reg_addr = 0;
volatile I2C_State_t i2c_state = I2C_STATE_IDLE;
volatile uint8_t i2c_rx_complete = 0;
volatile uint8_t i2c_tx_complete = 0;
volatile uint8_t  i2c_have_reg = 0;

// Function prototypes
void Application_Init(void);
void I2C_Slave_Config(void);
void I2C_ProcessCommand(void);
void Application_Task(void);
void Jump_To_Bootloader(void);

void Application_Init(void)
{
    SystemCoreClockUpdate();
    Delay_Init();
    USART_Printf_Init(115200);
    
    printf("\r\n=== CH32V006 Main Application v%d.%02d ===\r\n", 
           APPLICATION_VERSION >> 8, APPLICATION_VERSION & 0xFF);
    printf("Application start: 0x%08X\r\n", APPLICATION_START);
    printf("System Clock: %d Hz\r\n", SystemCoreClock);
    
    i2c_registers[0x00] = 0x00;  // Command register
    i2c_registers[0x01] = 0xAA;  // Status register (different from bootloader)
    i2c_registers[0x02] = (APPLICATION_VERSION >> 8) & 0xFF;  // Version high
    i2c_registers[0x03] = APPLICATION_VERSION & 0xFF;         // Version low
    i2c_registers[0x04] = 0x01;  // Config register (app mode)
    
    I2C_Slave_Config();
    printf("I2C Slave initialized at address 0x%02X\r\n", I2C_SLAVE_ADDRESS);
    
    RCC_PB2PeriphClockCmd(RCC_PB2Periph_GPIOD, ENABLE);
    
    GPIO_InitTypeDef gpio = {0};
    gpio.GPIO_Pin   = GPIO_Pin_3;
    gpio.GPIO_Mode  = GPIO_Mode_Out_PP;
    gpio.GPIO_Speed = GPIO_Speed_30MHz;
    GPIO_Init(GPIOD, &gpio);
    
    GPIO_SetBits(GPIOD, GPIO_Pin_3); 
    
    printf("Application initialization complete\r\n\r\n");
}

void I2C_Slave_Config(void)
{
    GPIO_InitTypeDef GPIO_InitStructure = {0};
    I2C_InitTypeDef  I2C_InitStructure = {0};
    NVIC_InitTypeDef NVIC_InitStructure = {0};
    
    RCC_PB2PeriphClockCmd(RCC_PB2Periph_GPIOC | RCC_PB2Periph_AFIO, ENABLE);
    RCC_PB1PeriphClockCmd(RCC_PB1Periph_I2C1, ENABLE);
    
    // Configure I2C pins (PC1 = SCL, PC2 = SDA)
    GPIO_InitStructure.GPIO_Pin = GPIO_Pin_1 | GPIO_Pin_2;
    GPIO_InitStructure.GPIO_Mode = GPIO_Mode_AF_OD;
    GPIO_InitStructure.GPIO_Speed = GPIO_Speed_30MHz;
    GPIO_Init(GPIOC, &GPIO_InitStructure);
    
    I2C_InitStructure.I2C_Mode = I2C_Mode_I2C;
    I2C_InitStructure.I2C_DutyCycle = I2C_DutyCycle_2;
    I2C_InitStructure.I2C_OwnAddress1 = I2C_SLAVE_ADDRESS << 1;
    I2C_InitStructure.I2C_Ack = I2C_Ack_Enable;
    I2C_InitStructure.I2C_AcknowledgedAddress = I2C_AcknowledgedAddress_7bit;
    I2C_InitStructure.I2C_ClockSpeed = 100000;
    
    I2C_Init(I2C1, &I2C_InitStructure);
    I2C_ITConfig(I2C1, I2C_IT_EVT | I2C_IT_BUF | I2C_IT_ERR, ENABLE);
    
    NVIC_InitStructure.NVIC_IRQChannel = I2C1_EV_IRQn;
    NVIC_InitStructure.NVIC_IRQChannelPreemptionPriority = 0;
    NVIC_InitStructure.NVIC_IRQChannelSubPriority = 0;
    NVIC_InitStructure.NVIC_IRQChannelCmd = ENABLE;
    NVIC_Init(&NVIC_InitStructure);
    
    NVIC_InitStructure.NVIC_IRQChannel = I2C1_ER_IRQn;
    NVIC_InitStructure.NVIC_IRQChannelPreemptionPriority = 0;
    NVIC_InitStructure.NVIC_IRQChannelSubPriority = 1;
    NVIC_Init(&NVIC_InitStructure);
    
    I2C_Cmd(I2C1, ENABLE);
    I2C_AcknowledgeConfig(I2C1, ENABLE);
}

void I2C1_EV_IRQHandler(void) __attribute__((interrupt("WCH-Interrupt-fast")));
void I2C1_EV_IRQHandler(void)
{
    // ---- Address matched (ADDR) ----
    if (I2C_GetFlagStatus(I2C1, I2C_FLAG_ADDR) != RESET) {
        (void)I2C1->STAR1;          // Read SR1
        (void)I2C1->STAR2;          // Then SR2 to clear ADDR
        i2c_have_reg = 0;           // Next RX byte will be the register index
        // Direction is in SR2.TRA: 0=Rx, 1=Tx (if you need branching here)
    }

    // ---- Byte received (RXNE) ----
    if (I2C_GetFlagStatus(I2C1, I2C_FLAG_RXNE) != RESET) {
        uint8_t b = I2C_ReceiveData(I2C1);
        if (!i2c_have_reg) {
            i2c_reg_addr = b;
            i2c_have_reg = 1;
        } else {
            if (i2c_reg_addr < I2C_BUFFER_SIZE) {
                i2c_registers[i2c_reg_addr++] = b;
            } // else: silently drop
        }
    }

    // ---- Transmit buffer empty (TXE) ----
    if (I2C_GetFlagStatus(I2C1, I2C_FLAG_TXE) != RESET) {
        uint8_t b = 0xFF;
        if (i2c_reg_addr < I2C_BUFFER_SIZE) {
            b = i2c_registers[i2c_reg_addr++];
        }
        I2C_SendData(I2C1, b);
    }

    // ---- STOP detected (STOPF) ----
    if (I2C_GetFlagStatus(I2C1, I2C_FLAG_STOPF) != RESET) {
        // Clear STOPF: read SR1 then write CR1 (CTLR1 on WCH)
        (void)I2C1->STAR1;
        I2C1->CTLR1 |= I2C_CTLR1_PE;   // re-write PE bit

        // Mark which path completed
        // If we received at least the register index, treat as RX done
        if (i2c_have_reg) {
            i2c_rx_complete = 1;
        } else {
            i2c_tx_complete = 1;
        }

        i2c_have_reg = 0; // reset for next transaction
    }
}

void I2C1_ER_IRQHandler(void) __attribute__((interrupt("WCH-Interrupt-fast")));
void I2C1_ER_IRQHandler(void)
{
    if (I2C_GetITStatus(I2C1, I2C_IT_AF))  { I2C_ClearITPendingBit(I2C1, I2C_IT_AF); }
    if (I2C_GetITStatus(I2C1, I2C_IT_BERR)){ I2C_ClearITPendingBit(I2C1, I2C_IT_BERR); }
    if (I2C_GetITStatus(I2C1, I2C_IT_OVR)) { I2C_ClearITPendingBit(I2C1, I2C_IT_OVR); }
}

void Jump_To_Bootloader(void)
{
    printf("Jumping to bootloader...\r\n");
    
    __disable_irq();
    I2C_Cmd(I2C1, DISABLE);
    RCC_PB1PeriphClockCmd(RCC_PB1Periph_I2C1, DISABLE);
    
    uint32_t* bootloader_vector = (uint32_t*)BOOTLOADER_START;
    uint32_t bootloader_stack = bootloader_vector[0];
    uint32_t bootloader_entry = bootloader_vector[1];
    
    __asm volatile(
        "mv sp, %0\n"      // Move bootloader_stack to stack pointer
        "jr %1\n"          // Jump to bootloader_entry address
        :
        : "r" (bootloader_stack), "r" (bootloader_entry)
        : "memory"
    );
    
    // Should never reach here
    while(1);
}

void I2C_ProcessCommand(void)
{
    uint8_t cmd = i2c_registers[0x00];
    
    switch(cmd)
    {
        case 0x01:  // Reset
            printf("Reset command received\r\n");
            Delay_Ms(100);
            NVIC_SystemReset();
            break;
            
        case 0x02:  // Get Status
            i2c_registers[0x01] = 0xAA;  // Application status
            break;
            
        case 0x03:  // Enter Bootloader
            printf("Enter bootloader command received\r\n");
            Delay_Ms(100);
            Jump_To_Bootloader();
            break;
            
        case 0x30:  // Start Update (redirect to bootloader)
            printf("Firmware update requested - jumping to bootloader\r\n");
            Delay_Ms(100);
            Jump_To_Bootloader();
            break;
            
        case 0x40:  // Get Device Info
            i2c_registers[0x10] = 0x32;  // '2' - CH32V006
            i2c_registers[0x11] = 0x01;  // Application variant
            i2c_registers[0x12] = 32;    // Flash size in KB
            i2c_registers[0x13] = 6;     // RAM size in KB
            i2c_registers[0x14] = (APPLICATION_VERSION >> 8) & 0xFF;
            i2c_registers[0x15] = APPLICATION_VERSION & 0xFF;
            printf("Device info requested\r\n");
            break;
            
        case 0x50:  // Application-specific command: Set LED
            if(i2c_registers[0x10] & 0x01)
            {
                GPIO_ResetBits(GPIOD, GPIO_Pin_3);  // LED ON
                printf("LED ON\r\n");
            }
            else
            {
                GPIO_SetBits(GPIOD, GPIO_Pin_3);   // LED OFF
                printf("LED OFF\r\n");
            }
            break;
            
        case 0x51:  // Application-specific command: Get GPIO state
            i2c_registers[0x10] = GPIO_ReadInputDataBit(GPIOD, GPIO_Pin_3) ? 0x00 : 0x01;
            printf("GPIO state requested\r\n");
            break;
            
        case 0x52:  // Application-specific command: Blink LED
            {
                uint8_t blink_count = i2c_registers[0x10];
                if(blink_count == 0) blink_count = 3;
                
                printf("Blinking LED %d times\r\n", blink_count);
                for(uint8_t i = 0; i < blink_count; i++)
                {
                    GPIO_ResetBits(GPIOD, GPIO_Pin_3);  // ON
                    Delay_Ms(200);
                    GPIO_SetBits(GPIOD, GPIO_Pin_3);    // OFF
                    Delay_Ms(200);
                }
            }
            break;
            
        default:
            printf("Unknown command: 0x%02X\r\n", cmd);
            i2c_registers[0x0B] = 0x01;  // Error: invalid command
            break;
    }
    
    // Clear command register
    i2c_registers[0x00] = 0x00;
}

void Application_Task(void)
{
    static uint32_t heartbeat_counter = 0;
    static uint8_t led_state = 0;
    
    heartbeat_counter++;
    if(heartbeat_counter >= 100)  // 1 second at 10ms loop
    {
        heartbeat_counter = 0;
        led_state = !led_state;
        
        if(led_state)
        {
            GPIO_ResetBits(GPIOD, GPIO_Pin_3);  // LED ON
            Delay_Ms(100);
            GPIO_SetBits(GPIOD, GPIO_Pin_3);    // LED OFF
        }
        
        static uint8_t heartbeat_value = 0;
        i2c_registers[0x05] = heartbeat_value++;
    }
}

int main(void)
{
    uint8_t i;
    
    Application_Init();
    
    printf("Application running - ready for I2C commands\r\n");
    printf("Commands:\r\n");
    printf("  0x01 - Reset\r\n");
    printf("  0x02 - Get Status\r\n");
    printf("  0x03 - Enter Bootloader\r\n");
    printf("  0x30 - Start Firmware Update\r\n");
    printf("  0x40 - Get Device Info\r\n");
    printf("  0x50 - Control LED (data in reg 0x10)\r\n");
    printf("  0x51 - Get GPIO State\r\n");
    printf("  0x52 - Blink LED (count in reg 0x10)\r\n\r\n");
    
    while(1)
    {
        if(i2c_rx_complete)
        {
            i2c_rx_complete = 0;
            printf("I2C data received\r\n");
            
            if(i2c_registers[0x00] != 0x00)
            {
                I2C_ProcessCommand();
            }
            
            printf("Registers: ");
            for(i = 0; i < 16; i++)
            {
                printf("%02X ", i2c_registers[i]);
            }
            printf("\r\n");
        }
        
        if(i2c_tx_complete)
        {
            i2c_tx_complete = 0;
            printf("I2C data transmitted\r\n");
        }
        
        // Application_Task();
        
        Delay_Ms(10);
    }
}

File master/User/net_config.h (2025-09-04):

/********************************** (C) COPYRIGHT *******************************
* File Name          : net_config.h
* Author             : WCH
* Version            : V1.30
* Date               : 2022/06/02
* Description        : This file contains the configurations of 
*                      Ethernet protocol stack library
*********************************************************************************
* Copyright (c) 2021 Nanjing Qinheng Microelectronics Co., Ltd.
* Attention: This software (modified or not) and binary are used for 
* microcontroller manufactured by Nanjing Qinheng Microelectronics.
*******************************************************************************/
#ifndef __NET_CONFIG_H__
#define __NET_CONFIG_H__

#ifdef __cplusplus
extern "C" {
#endif

/*********************************************************************
 * socket configuration, IPRAW + UDP + TCP + TCP_LISTEN = number of sockets
 */
#define WCHNET_NUM_IPRAW              1  /* Number of IPRAW connections */

#define WCHNET_NUM_UDP                1  /* The number of UDP connections */

#define WCHNET_NUM_TCP                0  /* Number of TCP connections */

#define WCHNET_NUM_TCP_LISTEN         0  /* Number of TCP listening */

/* The number of sockets, the maximum is 31  */
#define WCHNET_MAX_SOCKET_NUM         (WCHNET_NUM_IPRAW+WCHNET_NUM_UDP+WCHNET_NUM_TCP+WCHNET_NUM_TCP_LISTEN)

#define WCHNET_TCP_MSS                1460  /* Size of TCP MSS*/

#define WCHNET_NUM_POOL_BUF           (WCHNET_NUM_TCP*2+2)   /* The number of POOL BUFs, the number of receive queues */

/*********************************************************************
 * MAC queue configuration
 */
#define ETH_TXBUFNB                   2    /* The number of descriptors sent by the MAC  */

#define ETH_RXBUFNB                   7    /* Number of MAC received descriptors  */

#ifndef ETH_MAX_PACKET_SIZE
#define ETH_RX_BUF_SZE                1520  /* MAC receive buffer length, an integer multiple of 4 */
#define ETH_TX_BUF_SZE                1520  /* MAC send buffer length, an integer multiple of 4 */
#else
#define ETH_RX_BUF_SZE                ETH_MAX_PACKET_SIZE
#define ETH_TX_BUF_SZE                ETH_MAX_PACKET_SIZE
#endif

/*********************************************************************
 *  Functional configuration
 */
#define WCHNET_PING_ENABLE            1     /* PING is enabled, PING is enabled by default */

#define TCP_RETRY_COUNT               20    /* The number of TCP retransmissions, the default value is 20 */

#define TCP_RETRY_PERIOD              10    /* TCP retransmission period, the default value is 10, the unit is 50ms */

#define SOCKET_SEND_RETRY             0     /* Send failed retry configuration, 1: enable, 0: disable */

#define HARDWARE_CHECKSUM_CONFIG      0     /* Hardware checksum checking and insertion configuration, 1: enable, 0: disable */

#define FINE_DHCP_PERIOD              8     /* Fine DHCP period, the default value is 8, the unit is 250ms */

#define CFG0_TCP_SEND_COPY            1     /* TCP send buffer copy, 1: copy, 0: not copy */

#define CFG0_TCP_RECV_COPY            1     /* TCP receive replication optimization, internal debugging use */

#define CFG0_TCP_OLD_DELETE           0     /* Delete oldest TCP connection, 1: enable, 0: disable */

#define CFG0_IP_REASS_PBUFS           0     /* Number of reassembled IP PBUFs  */

#define CFG0_TCP_DEALY_ACK_DISABLE    1     /* 1: disable TCP delay ACK  0: enable TCP delay ACK */

/*********************************************************************
 *  Memory related configuration
 */
/* If you want to achieve a higher transmission speed,
 * try to increase RECE_BUF_LEN to (WCHNET_TCP_MSS*4)
 * and increase WCHNET_NUM_TCP_SEG to (WCHNET_NUM_TCP*4)*/
#define RECE_BUF_LEN                  (WCHNET_TCP_MSS*2)   /* socket receive buffer size */

#define WCHNET_NUM_PBUF               WCHNET_NUM_POOL_BUF   /* Number of PBUF structures */

#define WCHNET_NUM_TCP_SEG            (WCHNET_NUM_TCP*2)   /* The number of TCP segments used to send */

#define WCHNET_MEM_HEAP_SIZE    (16 * 1024)
// #define WCHNET_MEM_HEAP_SIZE          (((WCHNET_TCP_MSS+0x10+54+8)*WCHNET_NUM_TCP_SEG)+ETH_TX_BUF_SZE+64+2*0x18) /* memory heap size */

#define WCHNET_NUM_ARP_TABLE          50   /* Number of ARP lists */

#define WCHNET_MEM_ALIGNMENT          4    /* 4 byte alignment */
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

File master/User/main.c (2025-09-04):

/********************************** (C) COPYRIGHT *******************************
* File Name          : main.c
* Author             : WCH
* Version            : V1.0.0
* Date               : 2022/05/20
* Description        : Main program body.
*********************************************************************************
* Copyright (c) 2021 Nanjing Qinheng Microelectronics Co., Ltd.
* Attention: This software (modified or not) and binary are used for 
* microcontroller manufactured by Nanjing Qinheng Microelectronics.
*******************************************************************************/
/*
 *@Note
DHCP example, demonstrating that DHCP automatically obtains an IP address.
For details on the selection of engineering chips,
please refer to the "CH32V30x Evaluation Board Manual" under the CH32V307EVT\EVT\PUB folder.
*/
#include "string.h"
#include "eth_driver.h"

u8 MACAddr[6];                                    //MAC address
u8 IPAddr[4]   = {0, 0, 0, 0};                    //IP address
u8 GWIPAddr[4] = {0, 0, 0, 0};                    //Gateway IP address
u8 IPMask[4]   = {0, 0, 0, 0};                    //subnet mask
u8 DESIP[4]    = {192, 168, 1, 100};              //destination IP address
u16 desport = 1000;                               //destination port
u16 srcport = 1000;                               //source port

#define UDP_RECE_BUF_LEN 512
u8 SocketId;
u8 SocketRecvBuf[WCHNET_MAX_SOCKET_NUM][UDP_RECE_BUF_LEN]; // socket receive buffer
u8 MyBuf[UDP_RECE_BUF_LEN];

volatile uint32_t g_ms = 0;
static inline uint32_t millis(void) { return g_ms; }

#define I2C_SPEED              100000
#define I2C_MASTER_ADDRESS     0x3F
#define I2C_PAGE_SIZE          8
#define I2C_TIMEOUT            0x1000

void I2C_Config(void)
{
    GPIO_InitTypeDef GPIO_InitStructure = {0};
    I2C_InitTypeDef  I2C_InitStructure = {0};
    
    /* Enable GPIOB, I2C2 and AFIO clocks */
    RCC_APB2PeriphClockCmd(RCC_APB2Periph_GPIOB | RCC_APB2Periph_AFIO, ENABLE);
    RCC_APB1PeriphClockCmd(RCC_APB1Periph_I2C2, ENABLE);
    
    /* Configure PB10 (SCL) and PB11 (SDA) as AF Open-Drain */
    GPIO_InitStructure.GPIO_Pin = GPIO_Pin_10 | GPIO_Pin_11;
    GPIO_InitStructure.GPIO_Mode = GPIO_Mode_AF_OD;
    GPIO_InitStructure.GPIO_Speed = GPIO_Speed_50MHz;
    GPIO_Init(GPIOB, &GPIO_InitStructure);
    
    /* I2C configuration */
    I2C_InitStructure.I2C_Mode = I2C_Mode_I2C;
    I2C_InitStructure.I2C_DutyCycle = I2C_DutyCycle_2;
    I2C_InitStructure.I2C_OwnAddress1 = I2C_MASTER_ADDRESS;
    I2C_InitStructure.I2C_Ack = I2C_Ack_Enable;
    I2C_InitStructure.I2C_AcknowledgedAddress = I2C_AcknowledgedAddress_7bit;
    I2C_InitStructure.I2C_ClockSpeed = I2C_SPEED;
    
    /* Initialize I2C */
    I2C_Init(I2C2, &I2C_InitStructure);
    
    /* Enable I2C */
    I2C_Cmd(I2C2, ENABLE);
}

/*********************************************************************
 * @fn      mStopIfError
 *
 * @brief   check if error.
 *
 * @param   iError - error constants.
 *
 * @return  none
 */
void mStopIfError(u8 iError)
{
    if (iError == WCHNET_ERR_SUCCESS)
        return;
    printf("Error: %02X\r\n", (u16) iError);
}

/*********************************************************************
 * @fn      TIM2_Init
 *
 * @brief   Initializes TIM2.
 *
 * @return  none
 */
void TIM2_Init(void)
{
    TIM_TimeBaseInitTypeDef TIM_TimeBaseStructure = {0};

    RCC_APB1PeriphClockCmd(RCC_APB1Periph_TIM2, ENABLE);

    TIM_TimeBaseStructure.TIM_Period = SystemCoreClock / 1000000;
    TIM_TimeBaseStructure.TIM_Prescaler = WCHNETTIMERPERIOD * 1000 - 1;
    TIM_TimeBaseStructure.TIM_ClockDivision = 0;
    TIM_TimeBaseStructure.TIM_CounterMode = TIM_CounterMode_Up;
    TIM_TimeBaseInit(TIM2, &TIM_TimeBaseStructure);
    TIM_ITConfig(TIM2, TIM_IT_Update, ENABLE);

    TIM_Cmd(TIM2, ENABLE);
    TIM_ClearITPendingBit(TIM2, TIM_IT_Update);
    NVIC_SetPriority(TIM2_IRQn, 0x80);
    NVIC_EnableIRQ(TIM2_IRQn);
}

/*********************************************************************
 * @fn      WCHNET_DataLoopback
 *
 * @brief   Data loopback function.
 *
 * @param   id - socket id.
 *
 * @return  none
 */
void WCHNET_DataLoopback(u8 id)
{
#if 1
    u8 i;
    u32 len;
    u32 endAddr = SocketInf[id].RecvStartPoint + SocketInf[id].RecvBufLen;       //Receive buffer end address

    if ((SocketInf[id].RecvReadPoint + SocketInf[id].RecvRemLen) > endAddr) {    //Calculate the length of the received data
        len = endAddr - SocketInf[id].RecvReadPoint;
    }
    else {
        len = SocketInf[id].RecvRemLen;
    }
    i = WCHNET_SocketSend(id, (u8 *) SocketInf[id].RecvReadPoint, &len);        //send data
    if (i == WCHNET_ERR_SUCCESS) {
        WCHNET_SocketRecv(id, NULL, &len);                                      //Clear sent data
    }
#else
    u32 len, totallen;
    u8 *p = MyBuf;

    len = WCHNET_SocketRecvLen(id, NULL);                                //query length
    printf("Receive Len = %02x\n", len);
    totallen = len;
    WCHNET_SocketRecv(id, MyBuf, &len);                                  //Read the data of the receive buffer into MyBuf
    while(1){
        len = totallen;
        WCHNET_SocketSend(id, p, &len);                                  //Send the data
        totallen -= len;                                                 //Subtract the sent length from the total length
        p += len;                                                        //offset buffer pointer
        if(totallen)continue;                                            //If the data is not sent, continue to send
        break;                                                           //After sending, exit
    }
#endif
}

/*********************************************************************
 * @fn      WCHNET_HandleSockInt
 *
 * @brief   Socket Interrupt Handle
 *
 * @param   socketid - socket id.
 *          intstat - interrupt status
 *
 * @return  none
 */
void WCHNET_HandleSockInt(u8 socketid, u8 intstat)
{
    if (intstat & SINT_STAT_RECV) // receive data
    {
        WCHNET_DataLoopback(socketid); // Data loopback
    }
    if (intstat & SINT_STAT_CONNECT) // connect successfully
    {
        printf("TCP Connect Success\r\n");
    }
    if (intstat & SINT_STAT_DISCONNECT) // disconnect
    {
        printf("TCP Disconnect\r\n");
    }
    if (intstat & SINT_STAT_TIM_OUT) // timeout disconnect
    {
        printf("TCP Timeout\r\n");
    }
}
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

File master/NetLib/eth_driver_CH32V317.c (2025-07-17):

/********************************** (C) COPYRIGHT *******************************
* File Name          : eth_driver.c
* Author             : WCH
* Version            : V1.3.0
* Date               : 2022/06/02
* Description        : eth program body.
*********************************************************************************
* Copyright (c) 2021 Nanjing Qinheng Microelectronics Co., Ltd.
* Attention: This software (modified or not) and binary are used for 
* microcontroller manufactured by Nanjing Qinheng Microelectronics.
*******************************************************************************/

#include "string.h"
#include "eth_driver.h"

__attribute__((__aligned__(4))) ETH_DMADESCTypeDef DMARxDscrTab[ETH_RXBUFNB];       /* MAC receive descriptor, 4-byte aligned*/
__attribute__((__aligned__(4))) ETH_DMADESCTypeDef DMATxDscrTab[ETH_TXBUFNB];       /* MAC send descriptor, 4-byte aligned */

__attribute__((__aligned__(4))) uint8_t  MACRxBuf[ETH_RXBUFNB*ETH_RX_BUF_SZE];      /* MAC receive buffer, 4-byte aligned */
__attribute__((__aligned__(4))) uint8_t  MACTxBuf[ETH_TXBUFNB*ETH_TX_BUF_SZE];      /* MAC send buffer, 4-byte aligned */

__attribute__((__aligned__(4))) SOCK_INF SocketInf[WCHNET_MAX_SOCKET_NUM];          /* Socket information table, 4-byte alignment */
const uint16_t MemNum[8] = {WCHNET_NUM_IPRAW,
                         WCHNET_NUM_UDP,
                         WCHNET_NUM_TCP,
                         WCHNET_NUM_TCP_LISTEN,
                         WCHNET_NUM_TCP_SEG,
                         WCHNET_NUM_IP_REASSDATA,
                         WCHNET_NUM_PBUF,
                         WCHNET_NUM_POOL_BUF
                         };
const uint16_t MemSize[8] = {WCHNET_MEM_ALIGN_SIZE(WCHNET_SIZE_IPRAW_PCB),
                          WCHNET_MEM_ALIGN_SIZE(WCHNET_SIZE_UDP_PCB),
                          WCHNET_MEM_ALIGN_SIZE(WCHNET_SIZE_TCP_PCB),
                          WCHNET_MEM_ALIGN_SIZE(WCHNET_SIZE_TCP_PCB_LISTEN),
                          WCHNET_MEM_ALIGN_SIZE(WCHNET_SIZE_TCP_SEG),
                          WCHNET_MEM_ALIGN_SIZE(WCHNET_SIZE_IP_REASSDATA),
                          WCHNET_MEM_ALIGN_SIZE(WCHNET_SIZE_PBUF),
                          WCHNET_MEM_ALIGN_SIZE(WCHNET_SIZE_PBUF) + WCHNET_MEM_ALIGN_SIZE(WCHNET_SIZE_POOL_BUF)
                         };
__attribute__((__aligned__(4)))uint8_t Memp_Memory[WCHNET_MEMP_SIZE];
__attribute__((__aligned__(4)))uint8_t Mem_Heap_Memory[WCHNET_RAM_HEAP_SIZE];
__attribute__((__aligned__(4)))uint8_t Mem_ArpTable[WCHNET_RAM_ARP_TABLE_SIZE];

uint16_t gPHYAddress;
uint32_t volatile LocalTime;

ETH_DMADESCTypeDef *pDMARxSet;
ETH_DMADESCTypeDef *pDMATxSet;

volatile uint8_t LinkSta = 0;  //0:Link down 1:Link up
uint8_t LinkVaildFlag = 0;  //0:invalid 1:valid
uint8_t AccelerateLinkStep = 0;
uint8_t AccelerateLinkTime = 0;
uint8_t LinkProcessingStep = 0;
uint32_t LinkProcessingTime = 0;
uint32_t TaskExecutionTime = 0;
u16 LastPhyStat = 0;
u32 LastQueryPhyTime = 0;
void ETH_LinkDownCfg(void);
void PHY_FuncInit(void);
/*********************************************************************
 * @fn      WCHNET_GetMacAddr
 *
 * @brief   Get the MAC address
 *
 * @return  none.
 */
void WCHNET_GetMacAddr( uint8_t *p )
{
    uint8_t i;
    uint8_t *macaddr = (uint8_t *)(ROM_CFG_USERADR_ID+5);

    for(i=0;i<6;i++)
    {
        *p = *macaddr;
        p++;
        macaddr--;
    }
}

/*********************************************************************
 * @fn      WCHNET_TimeIsr
 *
 * @brief
 *
 * @return  none.
 */
void WCHNET_TimeIsr( uint16_t timperiod )
{
    LocalTime += timperiod;
}

/*********************************************************************
 * @fn      WCHNET_QueryPhySta
 *
 * @brief   Query external PHY status
 *
 * @return  none.
 */
void WCHNET_QueryPhySta(void)
{
    u16 phy_stat;
    if(QUERY_STAT_FLAG){                                         /* Query the PHY link status every 1s */
        LastQueryPhyTime = LocalTime / 1000;
        phy_stat = ETH_ReadPHYRegister( PHY_ADDRESS, PHY_BSR );
        if((phy_stat != LastPhyStat) && (phy_stat != 0xffff)){
            ETH_PHYLink();
        }
    }
}

/*********************************************************************
 * @fn      WCHNET_CheckPHYPN
 *
 * @brief   check PHY PN polarity
 *
 * @return  none.
 */
void WCHNET_CheckPHYPN(uint16_t time)
{
    u16 phy_stat;

    //check PHY PN
    if((LinkProcessingStep == 0)||(LocalTime >= LinkProcessingTime))
    {
        ETH_WritePHYRegister(gPHYAddress, 0x1F, 0x0 );
        phy_stat = ETH_ReadPHYRegister( gPHYAddress, 0x10);
        if(phy_stat & (1<<12))
        {
            if(LinkProcessingStep == 0)
            {
                LinkProcessingStep = 1;
                LinkProcessingTime = LocalTime + time;
            }
            else {
                LinkProcessingStep = 0;
                LinkProcessingTime = 0;
                phy_stat = ETH_ReadPHYRegister( gPHYAddress, PHY_ANER);
                if((time == 200) || ((phy_stat & 1) == 0))
                {
                    ETH_WritePHYRegister(gPHYAddress, 0x1F, 0x0 );
                    phy_stat = ETH_ReadPHYRegister( gPHYAddress, 0x16);
                    phy_stat |= 1<<5;
                    ETH_WritePHYRegister(gPHYAddress, 0x16, phy_stat );

                    phy_stat = ETH_ReadPHYRegister( gPHYAddress, 0x16);
                    phy_stat &= ~(1<<5);
                    ETH_WritePHYRegister(gPHYAddress, 0x16, phy_stat );

                    phy_stat = ETH_ReadPHYRegister( gPHYAddress, 0x1E);   /* Clear the Interrupt status */
                }
            }
        }
        else {
            LinkProcessingStep = 0;
            LinkProcessingTime = 0;
        }
    }
}
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

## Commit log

2025-07-08 add ch32v003 on pcb
    [hardware.kicad_pcb, hardware.kicad_sch]
2025-07-09 position capacitor + resistor + led with each ch32
    [hardware.kicad_pcb]
2025-07-11 add wiring ch32v006
    [hardware.kicad_pcb, hardware.kicad_sch]
2025-07-13 add ethernet wiring
    [hardware.kicad_pcb, hardware.kicad_sch]
2025-07-15 wiring ch32v307 + ethernet
    [hardware.kicad_pcb, hardware.kicad_sch]
2025-07-29 add external crystal
    [hardware.kicad_pcb, hardware.kicad_sch]
2025-08-03 update crystal + slave reset pull up
    [hardware.kicad_pcb, hardware.kicad_sch]
2025-08-04 crystal to gnd
    [hardware.kicad_pcb, hardware.kicad_sch]
2025-08-21 update ehernet wiring
    [hardware.kicad_pcb, hardware.kicad_sch]
2025-08-23 pass to 4 layers pcb
    [hardware.kicad_pcb, hardware.kicad_sch]
2025-08-26 add ethernet
    [hardware.kicad_pcb]
2025-08-26 update master code for dhcp working
    [hardware.kicad_pcb]
2025-08-26 add I2C function
2025-08-26 luanch i2c config
2025-08-26 add i2C slave minimal code
2025-08-26 upgrade 3.3 zone clearance
    [hardware.kicad_pcb]
2025-09-04 upgrade size
    [hardware.kicad_pcb]
2025-09-04 upgrade buffer number for master PHY socket
2025-09-04 i2c command slave work
